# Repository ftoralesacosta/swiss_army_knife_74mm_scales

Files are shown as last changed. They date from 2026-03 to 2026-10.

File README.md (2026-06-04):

# Swiss Army Knife Custom 74mm Scales

This is a collection of OpenSCAD scripts for creating scales for 74mm Swiss Army Knife models. I've been looking for a 74mm pen scale for a while. There was a version I never got the chance to download that took generic pen refills, but that has been lost since Shapeways went bankrupt. Originally this repo filled and stretched a 58mm scale. It now defines a standalone 74mm scale geometry. The dual slot scale uses this by itself, buth the pen scale still relies on the internal 58mm geometry for the pen-insert.

74mm Blue Pen Scale
74mm Red Dual Slot Scale

---

### 📜 Credits & Sources
The base 58mm geometries are derived from **Emil’s SAK Scales** on Thingiverse:
[Thing 5216489 - Victorinox 58mm Scales](https://www.thingiverse.com/thing:5216489/files)
The 58mm Pen Slider STL file is from **DizzyDane's Slider Piece** on Thingivers:
[Thing 6062753 - Victorinox 51mm Pen Slider](https://www.thingiverse.com/thing:6062753)

---

### Files and Organization
* STL files are in the top directory, and can be downloaded easily
    * BLANK Scale
    * Dual Slot Scale
    * Pen Scale BASE
    * Pen Scale PLUS pin slots
    * Pen Scale PLUS Pocket clip and pins
* OpensCAD
    * Source for generating STL files
    * Boolean edits for additional features and Pen Scale
    * Please edit! Would love PRs!

---
### 🛠️ Hardware Requirements
These scripts are optimized for a flush, high-tension fit. Standard 3.0mm inserts are too long for this profile and will bottom out.

* **Accessory Slots:**
  * Tweezers for 58mm models
  * Toothpick for 58mm models
  * *Note: Should test with Tortoise Gear ferro rod*
* **Pen Insert:**
  * Small pressurized pen
  * Grey pen holder insert
* **Pocket Clip & Hardware:**
  * [CIVIVI Deep Carry Pocket Clip](https://www.civivi.com/collections/accessories/products/civivi-2pcs-deep-carry-pocket-clip-ca-05d) (I used the shorter clip). Alternatively, any clip with a 4.5mm hole spacing and M2 screws will work.
  * 2.0mm tall threaded heat inserts for M2 screws *(Note: Most standard M2 inserts are 3.0mm tall, which is too long).*
* **Pins:**
  * Stainless steel pins from Victorinox.
  * The pin-holes are 35mm long and have a modeled diameter of 1.5mm (but will accept slightly smaller pins to account for 3D printing imperfections).

---

### 📦 Components

#### 1. 74mm Dual Accessory Scale
Defines a 74mm scale with dual-tool support.
* **Twin Slots:** Mirrored internal geometry for both Toothpick and Tweezers.
* **Geometry Preservation:** Uses `hull()` operations to stretch the length. This ensures the ergonomic curves of the 58mm tips remain intact rather than being linearly distorted.
* **Rivet Management:** Automatically plugs old rivet holes and generates new 3.8mm mounting points for the 74mm frame.

#### 2. 58mm → 74mm: Pen Scale
Converts the 58mm Pen Scale, prioritizing a factory-style finish.
* **OEM Drop-in:** Creates a scale that uses the original pen insert from the 58mm SAK with zero modifications needed.
* **Minkowski Rounding & Non-Linear Stretching:** Uses a sphere primitive to generate rounded edges that match the original scale shape, combined with independent X/Y axis stretching so the pen slot remains functional and aligned despite the size increase.
* **The "Snap":** Includes specific Y-axis cylinder subtractions and a shear-bottom cut to ensure the pen deploys with the right amount of tension.

#### 3. Adding Pocket Clip & Pins
Adds mounting points to an existing 74mm STL.
* **Threaded Inserts:** Modeled specifically for **2.0mm tall M2 heat-set threaded inserts**. *(Warning: Standard 3.0mm M2 inserts will punch right through the bottom of the scale.)*
* **Clip Spacing Specs:** * Holes are modeled exactly **4.6mm** apart. This is deliberately slightly wider than the physical 4.5mm CIVIVI clip spacing to account for print shrinkage.
  * 3.2mm diameter bore for the heat insert.
  * 2.2mm clearance for the screw.
* **Tension Fit Pins:** Uses "bowed" pin channels to ensure a tight interference fit on the original brass pins.

---

### 📝 ToDo's
* ~~Apply Minkowski rounding to the dual slot scale instead of the current split/stretch method.~~
* Utilize the side of the pen scale if no pins
    * pull-out tray?
    * interesting idea of a recessed cavity under a tweezer in the pen scale
* Figure out how to install the Leatherman micro bit driver.
* Indent the mounting area so the pocket clip sits flush with the scale (pending scale thickness checks).
* Fit another accessory slot for the pen scale that does not have a pocket clip.

### PR Requirements
* Maintain modularity
* Must be printed and tested, verified with link to picture of working feature

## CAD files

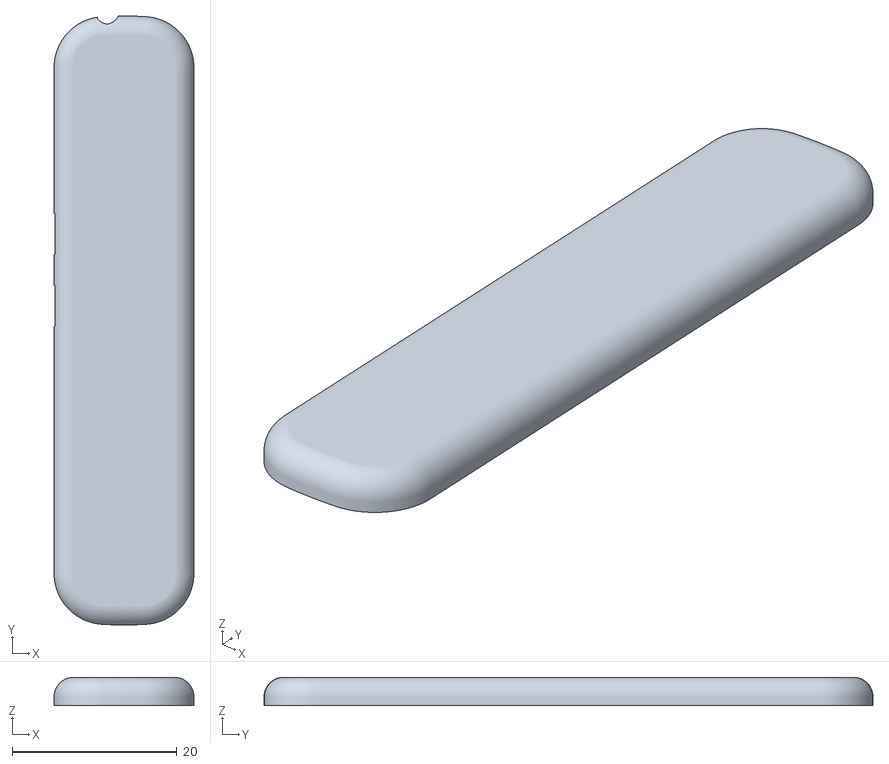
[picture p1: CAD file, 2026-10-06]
74mm_Pen_Scale_BASE.stl
17.0 x 74.0 x 3.45

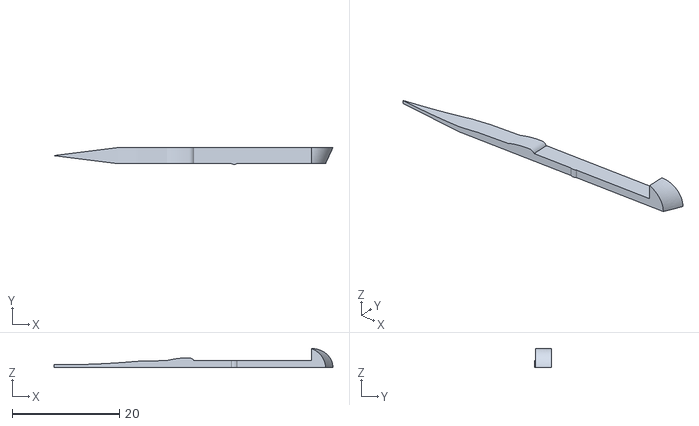
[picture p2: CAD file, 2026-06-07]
OpenScad/91mm_Toothpick.stl
51.9 x 3.13 x 3.55

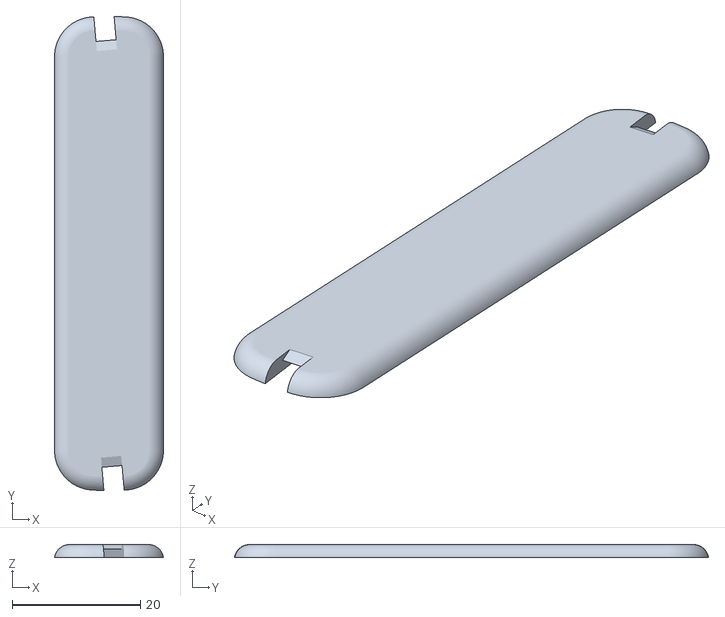
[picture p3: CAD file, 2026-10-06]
74mm_Dual_Slot_Scale.stl
17.0 x 74.0 x 2.00

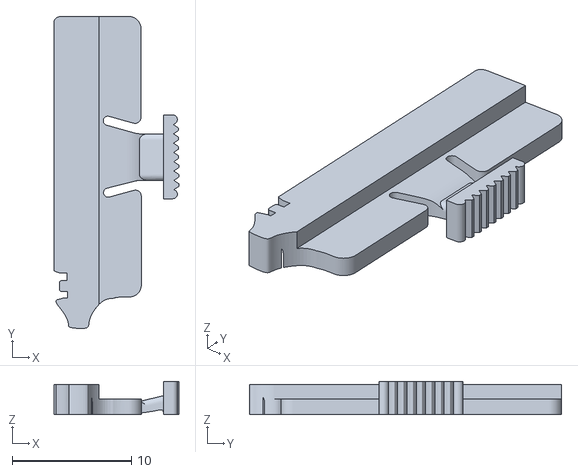
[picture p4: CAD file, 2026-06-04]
OpenScad/Victorinox_58mm_Pen_slider_piece.stl
10.5 x 26.1 x 2.80

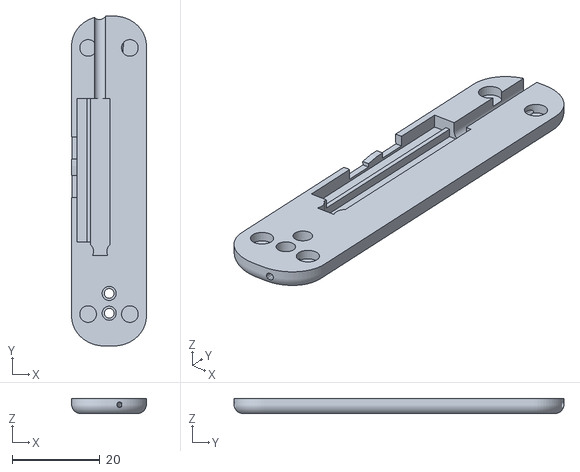
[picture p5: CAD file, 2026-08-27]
74mm_Pen_Scale_PLUS_Pins_PocketClip.stl
17.0 x 75.0 x 3.45

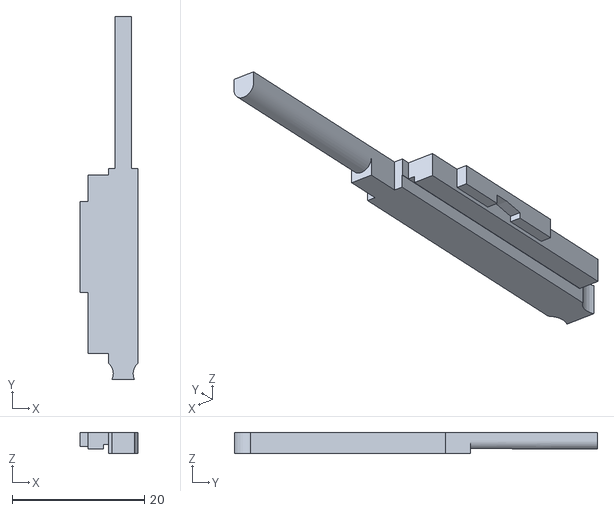
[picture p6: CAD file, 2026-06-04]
OpenScad/pen_insert_positive.stl
8.70 x 54.9 x 3.25

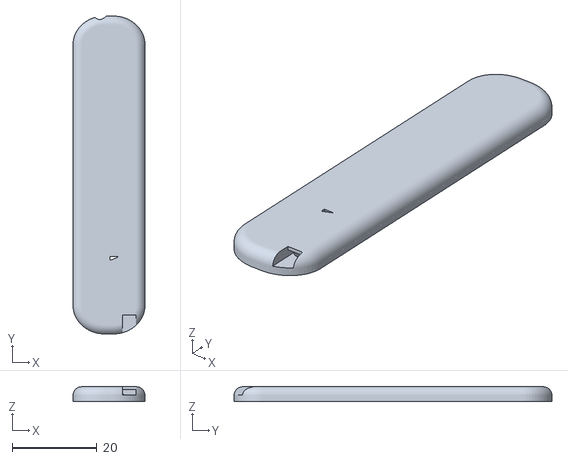
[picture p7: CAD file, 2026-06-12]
74mm_Pen_Scale_Ultra.stl
17.0 x 75.0 x 3.45

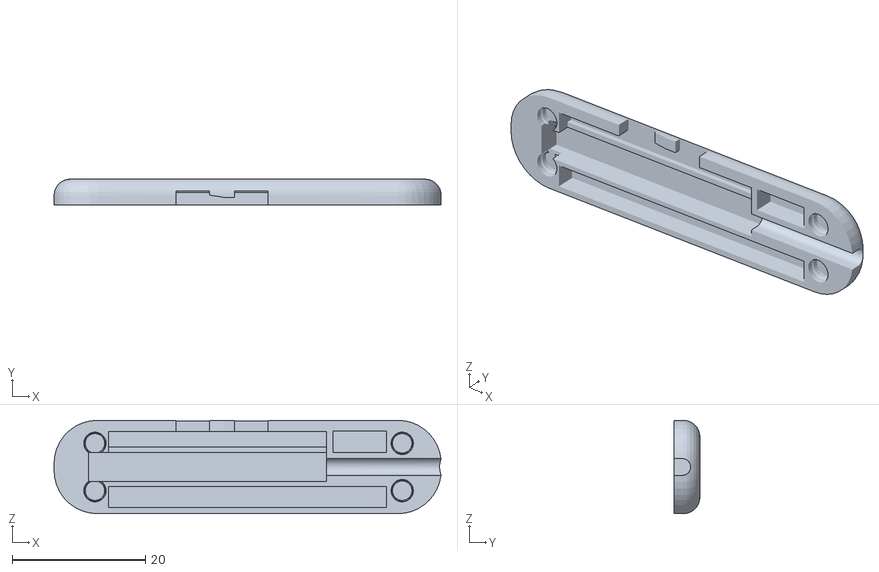
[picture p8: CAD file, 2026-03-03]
OpenScad/sak58mmscales-pen.stl
58.1 x 3.90 x 14.0

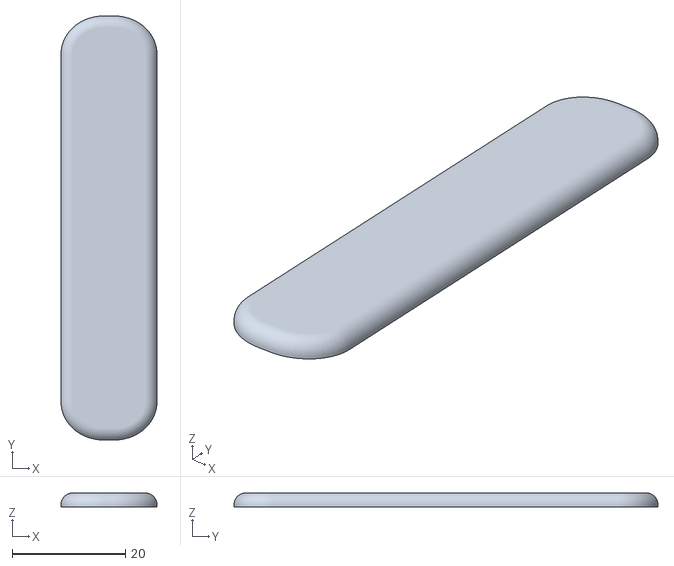
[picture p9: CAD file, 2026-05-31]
74mm_BLANK Scale.stl
17.0 x 75.0 x 2.50

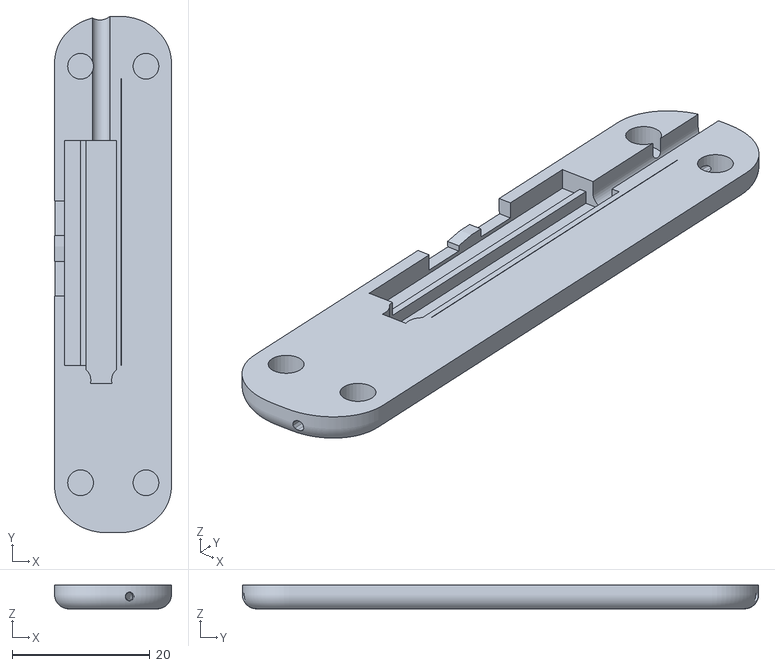
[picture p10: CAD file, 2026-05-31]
74mm_Pen_Scale_PLUS_Pins.stl
17.0 x 75.0 x 3.45

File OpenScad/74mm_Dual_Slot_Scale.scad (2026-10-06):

// --- File Setup & Core Dimensions ---
target_len     = 74;   // End-to-end. (Was 75: overhung the 74mm liner by ~0.5 at each end)
target_width   = 17.0; // Carefully dialed-in width for 74mm scale
target_thick   = 2.0;  // (was 2.5 - printed slightly taller than the toothpick/tweezers)
$fn = 60; // Global smoothness

// --- Minkowski Configuration ---
mask_offset_x = 0; // Perfectly centered
mask_offset_y = 0; // Perfectly centered
mask_edge_radius = 2.1; // (legacy - only used by sak_scale_rounded())

// --- Edge Profile (cross-section of the rounded edge) ---
// Measured from a photo of a genuine Victorinox small toothpick (IMG_2339):
// the head end is a single circular arc, R = 2.4 mm (+/- ~0.1), fit error < 0.03 mm.
// The arc is placed tangent to the top face so it blends smoothly (no crease):
// center at Z = target_thick - R (= -0.4 at 2.0 mm thick, so the arc starts just
// below the base and the edge meets the bottom face ~10 deg off vertical).
edge_profile_radius = 2.4;
edge_arc_center_z   = target_thick - edge_profile_radius;
edge_profile_steps  = 24;   // Number of slices used to build the arc

// --- Accessory Channels (Tweezers/Toothpick Slots) ---
enable_accessory_channels = true;
channel_width = 3.15; 
channel_length = 46; 
channel_height = 1.3; 

// Position relative to flat bottom face at Z = 0
channel_pos_x = -3.2;         
channel_pos_y = 8.6;          
channel_angle = 185.0;        
channel_pos_z = channel_height / 2; // Starts exactly at Z = 0

// Channel Stiffener: the channel gets shallower toward its inner end (the middle of
// the scale, where both channels overlap and the scale wants to bend). Material is
// added inside the channel only - the scale height is unchanged.
// Sized to follow the toothpick's point taper (STL: 1.32 thick until ~9.6 mm from
// the point, tapering to 0.55 at the point; point sits ~1.5 mm from the inner end).
enable_channel_taper = true;
channel_taper_length = 11;   // Distance from the inner end over which depth ramps (was 12; toothpick now seats 1 mm deeper)
channel_inner_depth  = 0.6;  // Channel depth at the very inner end (full = channel_height)

// Notch Settings (The opening for the tool head)
// The toothpick head's shoulder butts against the notch's inner wall
// (notch_start_pos), so this sets how far in the toothpick goes.
notch_length = 5.5;           // (was 4.5; +1 so the notch's outer end stays put)
notch_start_pos = 42;         // (was 43; tools overhung the liner edge by ~1 mm)
notch_depth_offset = 2.25;    
notch_height = 6.0;

// Nail Nick (ramp behind the tool head so a fingernail can lift it out)
// Starts at the top surface nail_nick_length before the notch wall and slopes
// down toward the knife (Z = 0) to nail_nick_bottom_z at the notch wall.
// Ending at the channel top (1.3) exposes the head's shoulder above the shank.
enable_nail_nick  = true;
nail_nick_length  = 1.5;
nail_nick_bottom_z = channel_height;

// --- Pin Channel Settings (Optional) ---
enable_pin_slot = false;
pin_width = 1.0; 
pin_length = 45.0;        
pin_pos_x = 4.3;          
pin_pos_y = 14.5;
pin_pos_z = 1.0;
pin_angle = 186.0; 

// --- New Rivet Holes ---
hole_dist_y   = 60.5 / 2; 
hole_dist_x   = 9.5 / 2; 
hole_dia      = 3.8;
hole_height   = 1.9; // Pocket depth 1.4 + 0.5 below Z = 0. (Was 2.1 / 1.6 deep: only 0.4 mm
                     // of skin left on the 2.0 mm scale. Set back to 2.1 if pins don't seat.)
hole_z_offset = -0.5; // Starts below Z = 0 for a clean cut
hole_nudge_x  = 0; // Perfectly centered
hole_nudge_y  = 0; // Perfectly centered

// --- Debug Config ---
show_center_lines = false;


// --- Mathematical Geometry Modules ---

// Plan-view outline (same plane as the liners) - compound curve per end:
//   straight side -> corner arc (profile_corner_radius) -> flat end arc (profile_end_radius)
// All arcs are tangent. A large end radius makes the end flatten out quickly from
// the corner, like the aluminum liner, instead of bulging like a single radius.
// Defaults keep the corners where the old R7.5 ellipse put them; only the
// middle of the end comes in (0.5 mm), giving 74 mm overall.
profile_corner_radius = 6.2;
profile_end_radius    = 45;

// Derived: corner-circle center (x, y) and the end arc's tangent point.
_pc_x  = target_width/2 - profile_corner_radius;
_pe_cy = target_len/2 - profile_end_radius;                   // end-arc center y
_pc_y  = _pe_cy + sqrt(pow(profile_end_radius - profile_corner_radius, 2) - _pc_x*_pc_x);
_pt_x  = _pc_x * profile_end_radius / (profile_end_radius - profile_corner_radius);

module sak_profile_2d() {
    translate([mask_offset_x, mask_offset_y])
    hull() {
        // Four corner arcs
        for (sx = [-1, 1], sy = [-1, 1])
            translate([sx * _pc_x, sy * _pc_y]) circle(r = profile_corner_radius, $fn = 120);
        // Two flat end arcs (only the part between the corner tangent points)
        for (sy = [-1, 1])
            mirror([0, sy < 0 ? 1 : 0])
            intersection() {
                translate([0, _pe_cy]) circle(r = profile_end_radius, $fn = 720);
                translate([-_pt_x, _pc_y]) square([2 * _pt_x, target_len]);
            }
    }
}

// Previous outline (hull of 4 R7.5 x 6.75 ellipses) - kept for reference.
module sak_profile_2d_legacy(rad = 7.5, elong = 0.9) {
    hull() {
        for (x = [-1, 1], y = [-1, 1]) 
            translate([x * (target_width/2 - rad) + mask_offset_x, y * (75/2 - (rad * elong)) + mask_offset_y])
            scale([1, elong]) circle(r=rad);
    }
}

module sak_scale_rounded(thickness=5, edge_radius=1.5) {
    minkowski() {
        // Core shape (shrunken so the sphere doesn't make it oversized)
        linear_extrude(height = thickness - 2*edge_radius, center=true)
            offset(r = -edge_radius)
            sak_profile_2d();
            
        // The sphere that adds the curve to Top AND Bottom
        sphere(r = edge_radius);
    }
}

// Horizontal inset of the edge at height z, relative to the full footprint at Z = 0.
// Arc of radius R centered at height zc; vertical wall below zc.
function _edge_w(z, R, zc) = z <= zc ? R : sqrt(max(0, R*R - pow(z - zc, 2)));
function edge_inset(z, R, zc) = _edge_w(0, R, zc) - _edge_w(z, R, zc);

module sak_74mm_solid_body(thick = target_thick, R = edge_profile_radius, zc = undef) {
    z_c = is_undef(zc) ? thick - R : zc;   // default: arc tangent to the top face
    assert(thick <= z_c + R + 1e-9, "Scale is thicker than the edge arc's top (arc center + edge_profile_radius)");
    // Profile and arc are both convex, so a hull of thin offset slices
    // reproduces the solid exactly (and much faster than minkowski).
    eps = 0.01;
    hull() {
        // Slices at Z = 0 and evenly spaced in angle around the arc
        zs = concat([0], [for (i = [0 : edge_profile_steps])
                          let(zz = z_c + R * sin(90 * i / edge_profile_steps))
                          if (zz > 0 && zz < thick) zz], [thick - eps]);
        for (z0 = zs) {
            z = min(z0, thick - eps);
            translate([0, 0, z])
                linear_extrude(height = eps)
                offset(delta = -edge_inset(z, R, z_c))
                sak_profile_2d();
        }
    }
}

// Previous body (R2.1 sphere minkowski, sliced flat at the top) - kept for reference.
module sak_74mm_solid_body_legacy(thick = target_thick) {
    difference() {
        // 1. Generate double-thickness rounded scale centered at Z = 0
        sak_scale_rounded(thickness = 2.5 * 2, edge_radius = mask_edge_radius);
        
        // 2. Cut off the bottom half to leave a perfectly flat bottom face at Z = 0
        translate([-100, -100, -200])
            cube([200, 200, 200]);
            
        // 3. Slice off the top to the desired thickness
        translate([-100, -100, thick])
            cube([200, 200, 200]);
    }
}

module new_rivet_holes() {
    for(x = [-1, 1], y = [-1, 1]) {
        translate([x * hole_dist_x + hole_nudge_x, y * hole_dist_y + hole_nudge_y, hole_z_offset]) 
            cylinder(h=hole_height, d=hole_dia, $fn=30);
    }
}
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

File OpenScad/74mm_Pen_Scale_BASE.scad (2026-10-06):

// ============================================================================
// 74mm SAK Pen Scale BASE
// ============================================================================
// Integrates the pen cavity insert into the 74mm Swiss Army Knife scale.
// Resolves coordinates so that the flat bottom face of the scale is perfectly flush
// with the flat face of the pen insert.
// ============================================================================

$fn = 60; // Smoothness

// --- CONFIGURATION ---

// Choose base geometry source:
// true  = Use mathematical model from 74mm_Dual_Slot_Scale.scad (cleaner, parametric)
// false = Import pre-rendered "74mm_BLANK Scale.stl" from parent directory
use_mathematical_geometry = true;

// Choose pen insert source:
// true  = Generate live using pen_cavity_impression() module from pen_insert_positive.scad
// false = Import pre-rendered "pen_insert_positive.stl"
use_live_pen_impression = false;

// Set to true to preview the pen insert plug in red (ghost overlay in preview mode)
preview_pen_insert = false;

// --- THICKNESS CONFIGURATION ---
// Standard SAK 74mm scales are 2.5mm thick.
// SAK Pen scales need to be thicker (e.g. 3.45mm) to house the pen cavity.
target_thickness = 3.45;
extra_thickness = target_thickness - 2.5;

// --- RIVET HOLE CONFIGURATION ---
// Depth of the rivet holes into the flat face of the scale (standard is 1.6mm)
rivet_hole_depth = 1.6;

// --- PEN CAVITY POSITIONING & FRICTION TUNING ---
pen_offset_x = -2.0; // Left/right shift
pen_offset_y = 10.0; // Up/down shift
pen_offset_z = -0.30; 
// Offset Z is important. More negative values make for a tighter fit. This may
// need adjusting. Works for 0.4mm PETG and PLA. If the insert rattles in the scale
// make pen_offset_z more negative. If it's too difficult to actuate the pen, make less negative

// Total length of the narrow tip channel (matches the plug tip length)
pen_tip_length = 23.0;

// --- LIBRARY IMPORTS ---
use <74mm_Dual_Slot_Scale.scad>
use <pen_insert_positive.scad>

// --- GEOMETRY GENERATORS ---

module blank_scale_base() {
    if (use_mathematical_geometry) {
        sak_74mm_solid_body();
    } else {
        import("../74mm_BLANK Scale.stl");
    }
}

module pen_insert_plug() {
    if (use_live_pen_impression) {
        pen_cavity_impression(tip_length = pen_tip_length);
    } else {
        import("pen_insert_positive.stl");
    }
}

module deepen_tip_channel(length) {
    // Deepens the tip channel from Y = 8.0 to Y = 8.0 + length by 0.75 mm in Z
    translate([0, 8.0, -0.75])
        aligned_channel(length);
}

// Solid cylinders that match the position and height of pre-existing rivet holes 
// in the imported STL. Used to completely fill them so we can drill them to a uniform depth.
module rivet_fillers(extra_thick) {
    h_dist_y   = 60.5 / 2; 
    h_dist_x   = 9.5 / 2; 
    h_dia      = 3.8 + 0.1; // Slightly larger diameter to ensure a clean union/merge
    h_height   = 2.1; 
    h_z_offset = extra_thick - 0.5; // Offset starts exactly where the translated STL's holes are
    
    for(x = [-1, 1], y = [-1, 1]) {
        translate([x * h_dist_x, y * h_dist_y, h_z_offset]) 
            cylinder(h=h_height, d=h_dia, $fn=30);
    }
}

// Clean rivet holes subtraction with custom depth
module rivet_holes_subtraction(depth) {
    h_dist_y   = 60.5 / 2; 
    h_dist_x   = 9.5 / 2; 
    h_dia      = 3.8;
    h_height   = depth + 0.5; // Include 0.5mm starting depth below Z = 0
    h_z_offset = -0.5; 
    
    for(x = [-1, 1], y = [-1, 1]) {
        translate([x * h_dist_x, y * h_dist_y, h_z_offset]) 
            cylinder(h=h_height, d=h_dia, $fn=30);
    }
}

module base_scale_solid() {
    if (use_mathematical_geometry) {
        union() {
            // Flat extension at the bottom
            linear_extrude(height = extra_thickness)
                sak_profile_2d();
                
            // Original rounded scale shifted up (2.5 mm, so total = target_thickness)
            translate([0, 0, extra_thickness])
                sak_74mm_solid_body(thick = target_thickness - extra_thickness);
        }
    } else {
        union() {
            // Flat extension at the bottom
            linear_extrude(height = extra_thickness)
                sak_profile_2d();
                
            // Original rounded scale shifted up
            translate([0, 0, extra_thickness])
                import("../74mm_BLANK Scale.stl");
                
            // Fill the rivet holes of the imported STL
            rivet_fillers(extra_thickness);
        }
    }
}

// --- FINAL ASSEMBLY ---

// Optional preview overlay
if (preview_pen_insert) {
    %color("Red")
    translate([pen_offset_x, pen_offset_y, pen_offset_z])
    translate([0, 0, 1.25])
    mirror([0, 0, 1])
    union() {
        pen_insert_plug();
        deepen_tip_channel(pen_tip_length);
    }
}

difference() {
    base_scale_solid();
    
    // Drill clean rivet holes to the exact custom depth
    rivet_holes_subtraction(rivet_hole_depth);
    
    // Position and subtract the pen insert:
    // - Flat face of pen_insert_plug() is at Z = 1.25.
    // - Mirror Z flips the cavity upwards so it cuts into the scale body (Z > 0).
    // - Translate by [0, 0, 1.25] places its flat face at Z = 0.
    // - pen_offset_z can be adjusted to tune the cavity depth/fit tightness.
    translate([pen_offset_x, pen_offset_y, pen_offset_z])
    translate([0, 0, 1.25])
    mirror([0, 0, 1])
    union() {
        pen_insert_plug();
        deepen_tip_channel(pen_tip_length);
    }
}

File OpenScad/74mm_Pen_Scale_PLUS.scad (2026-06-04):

// --- 1. File Configuration ---
file_74mm = "../74mm_Pen_Scale_BASE.stl";
$fn = 60; // Smoothness
enable_pocket_clip = false;  // Toggle the pocket clip screw holes
enable_pins    =     true;  // Toggle the pin slots

// --- Centering & Debug ---
left_edge = -5.7;
right_edge = 10.6;
scale_center = (left_edge + right_edge) / 2;
show_center_lines = false;
if (show_center_lines) {
    translate([scale_center, 0, 6])
    %color("Black") cube([0.1, 100, 0.5], center=true);
    translate([0.0, -12.5, 6])
    %color("Black") cube([100, 0.1, 0.5], center=true);
}

// --- 2. Hole Configuration ---

// A. Insert Settings (The wide part for the brass nut)
hole_diameter = 3.2; 
hole_height   = 2.0;

// B. Screw Clearance Settings (The narrow part for the screw to pass through)
screw_diameter = 2.2;  // 2.2mm allows an M2 screw to slide through easily
screw_depth    = 6.0;  // How deep the screw hole goes (should be > hole_height)

// C. Clip Settings
// Civivi Deep Carry clips are usually 4.5mm spacing.
clip_hole_spacing = 4.5; 

// --- 3. Position the Holes ---
// CHANGE THESE NUMBERS to move the holes to the right spot
// Note: These coordinates are relative to the world, not the STL's local origin
pos_x = scale_center+0.3;  
pos_y = -7.2; 
pos_z = 5.0;  // Z-height entry point. To make holes perfectly flush with the flat face, this should match the scale's translation Z (which is 4.0). Adjust this if you shift the scale.

rot_x = 0;
rot_y = 180;
rot_z = 90;   // Rotate this if the clip needs to be angled

// --- 4. Pin Channel Settings ---
pin_width = 1.3;         
pin_length = 35.0;       
pin_pos_x = -5.0;         
pin_pos_y = -2.7;
pin_pos_z = 1.5;
pin_angle = 91.0;    


// --- 5. The Geometry ---
difference() {
    // A. The Part (Imported & Moved as you requested)
    color("yellow", 1.0) 
    translate([2.71, 18.35, 4.95]) 
    mirror([0, 0, 1])
    import(file_74mm);

    // B. The Holes to Cut
    // The '#' sign makes the holes appear red/transparent so you can see them!
    #translate([pos_x, pos_y, pos_z])
    rotate([rot_x, rot_y, rot_z])
    civivi_holes();
}

// --- Modules ---

module civivi_holes() {
    union() {
        if (enable_pocket_clip) {
            // Hole 1 Stack
            make_hole_stack();
            
            // Hole 2 Stack (offset by 4.5mm)
            translate([clip_hole_spacing, 0, 0])
            make_hole_stack();
        }
        
        if (enable_pins) {
            // B. Pin Channel
            translate([pin_pos_x, pin_pos_y, pin_pos_z])
            rotate([0, 0, pin_angle]) // Only rotate on Z to align with the pen body
            curved_pin_channel(pin_length, pin_width, 0.5);
            
            // C. Second Pin Channel
            translate([pin_pos_x-41, pin_pos_y, pin_pos_z])
            rotate([0, 0, pin_angle]) // Only rotate on Z to align with the pen body
            curved_pin_channel(pin_length, pin_width, 0.5);
        }
    }
}

module make_hole_stack() {
    union() {
        // 1. The Insert Hole (Wide, Shallow)
        cylinder(h = hole_height, d = hole_diameter);
        
        // 2. The Screw Hole (Narrow, Deep)
        // We start this at 0 too, so it goes all the way through the insert area
        // down into the plastic.
        cylinder(h = screw_depth, d = screw_diameter);
    }
}

module curved_pin_channel(length, diameter, x_offset) {
    steps = 4; 
    render() 
    for (i = [0 : steps - 1]) {
        // progress along the length (Y-axis)
        y_pos1 = (i / steps) * length;
        y_pos2 = ((i + 1) / steps) * length;
        
        // Offset amount (X-axis) creating the bow
        x_off1 = sin((i / steps) * 180) * x_offset;
        x_off2 = sin(((i + 1) / steps) * 180) * x_offset;

        hull() {
            // Keep Z at 0 to ensure no vertical curve
            translate([x_off1, y_pos1 - length/2, 0])
                sphere(d = diameter, $fn=12); // Using spheres for cleaner hulls at angles
            translate([x_off2, y_pos2 - length/2, 0])
                sphere(d = diameter, $fn=12);
        }
    }
}

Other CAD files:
OpenScad/74mm_Pen_Scale_Ultra.scad
OpenScad/74mm_Titanium_Pry_Scale.scad
OpenScad/pen_insert_positive.scad

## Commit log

2026-03-03 major file submissions
    [OpenScad_74mm.scad, OpenScad_74mm.stl, OpenScad_74mm_PenScale.scad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]
2026-05-12 Update OpenScad_74mm_PenScale.scad
    gives more space to the pen, without it rattling. Still good friction fit
    [OpenScad_74mm_PenScale.scad]
2026-05-12 Add files via upload
    Slightly increases scale thickness by ~0.2mm. This reduces the friction just enough so that the pen insert can glide in and out without getting stuck, but keeps the scale tight enough where the insert won't rattle.
    [OpenScad_74mm_PenScale.scad, OpenScad_74mm_PenScale.stl, OpenScad_74mm_PenScale_POCKETCLIP.scad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]
2026-05-31 updated dual slot scale
    Refactors the dual slot scale with the geometry I learned from the pen scale.
    Initially, I filled and stretched a 58mm scale, and then added dual slots. This was messy but I didn't understand the geometry of the scale at the time.
    The pen scale forced me to understand it, and I apply it now. It fills a geometry, and then subtracts rivet holes and tool slots
    [OpenScad_74mm.scad, OpenScad_74mm.stl]
2026-05-31 update README after geometry edits to dual slot
2026-05-31 moved stl pen w/ pin
    [74mm_Pen_Scale_PLUS_Pins.stl, OpenScad_74mm_PenScale_Add_PocketClip_and_Pins.scad]
2026-06-01 pen scale with pin slot and pocket clip holes
    [74mm_Pen_Scale_PLUS.scad, 74mm_Pen_Scale_PLUS_Pins_PocketClip.stl]
2026-06-01 rm old files
    [OpenScad_74mm_PenScale.scad, OpenScad_74mm_PenScale.stl, OpenScad_74mm_PenScale_Add_PocketClip_and_Pins.scad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]
2026-06-01 cleaning up files
    [74mm_Pen_Scale_PLUS_Pins.stl, OpenScad_74mm.scad, OpenScad_74mm.stl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]
2026-06-03 creates positive impression of pen slot
    [pen_insert_positive.scad]
2026-06-03 fixes artifact near tip
    [pen_insert_positive.scad]
2026-06-03 pen insert plug for subtracting from scales
    [pen_insert_positive.stl]
2026-06-04 Base Scale now uses pen_insert positive file
    [74mm_Pen_Scale_BASE.scad, 74mm_Pen_Scale_BASE.stl, pen_insert_positive.scad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]
2026-06-04 pen holder insert STL
    [Victorinox_58mm_Pen_slider_piece.stl]
2026-06-04 pen channel is deeper for smoother pen action
    [74mm_Pen_Scale_BASE.scad, 74mm_Pen_Scale_BASE.stl]
2026-06-04 fixed PLUS scales for updates to BASE
    [74mm_Pen_Scale_PLUS.scad, 74mm_Pen_Scale_PLUS_Pins.stl, 74mm_Pen_Scale_PLUS_Pins_PocketClip.stl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]
2026-06-04 First draft of ultra pen scale. Adds another scale tool
    [74mm_Pen_Scale_Ultra.scad]
2026-06-07 takes toothpick for 91mm scale
    [91mm_Toothpick.stl]
2026-06-08 Adding needle slot to ultimate scale. Previous directory change seems to be tripping up local git
    [74mm_Pen_Scale_Ultra.scad]
2026-06-08 playing around with pry-bar scale geometry
    [74mm_Titanium_Pry_Scale.scad]
2026-06-08 Adding smoothing the taper
    [74mm_Titanium_Pry_Scale.scad]
2026-06-08 refining shape
    [74mm_Titanium_Pry_Scale.scad]
2026-06-09 fixed bug in pen insert
    [74mm_Pen_Scale_BASE.stl, 74mm_Pen_Scale_PLUS.stl]
2026-06-12 fixed pen scale Y to prevent poking out. Fixed BASE
    [74mm_Pen_Scale_BASE.stl, 74mm_Pen_Scale_Ultra.stl]
2026-07-20 fixed mirrored cavity
    [74mm_Pen_Scale_BASE.stl]
2026-07-20 remove redundant file
    [74mm_Pen_Scale_PLUS.stl]
2026-08-27 adding option for clip indent
    [74mm_Pen_Scale_PLUS_Pins_PocketClip.stl]
2026-10-06 Dual Slot scale: R2.4 edge, flatter ends (74mm), 2.0mm thick, nail nicks, channel stiffener; pen BASE thickness fix
    [74mm_Dual_Slot_Scale.scad, 74mm_Dual_Slot_Scale.stl, 74mm_Pen_Scale_BASE.scad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]
